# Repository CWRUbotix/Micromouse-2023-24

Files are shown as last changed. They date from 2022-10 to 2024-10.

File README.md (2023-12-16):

# Micromouse 2023-24 🐁

A fully autonomous maze-solving not-quite-mouse-sized robot. 

## Folders

```
.
├── LICENSE	     # License (woohoo)
├── README.md    # This file
├── cad          # 3D-models and designs
├── pcb          # Hardware-related designs and component docs
└── software     # Soft/firmware for the robot
```

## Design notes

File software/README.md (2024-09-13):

# Micromouse Software Setup 2025

# Table of Contents

1. [Setup Git Repo](#setup-git-repo)

2. [Install Arduino IDE](#install-arduino-ide)
    1. [Enable Teensy Support](#enable-teensy-support)
3. [Install Mouse Simulator](#install-mouse-simulator)
    1. [Install C Compiler GCC](#install-c-compiler-gcc)
    2. [Run the Simulator](#to-run-the-simulator)
    3. [OPTIONAL - Install QT Creator](#optional-install-qt-creator)

# Setup Git Repo
If you already have Git or Git Desktop installed, you can skip to [Cloning the Git Repo](#cloning-the-git-repo)  
If you want do version control from the command line and forgo opening another application to push your changes to the repository, just download [Git](https://git-scm.com/downloads).  
Otherwise, if you'd like to forgo using the command line and use a GUI instead, install [GitHub Desktop](https://desktop.github.com/download/) in addition to Git.  
## Cloning the Git Repo
Open up a terminal like `Git Bash`, and `cd` from the current directory to the directory that you want to have the repository
```bash
cd folder/folder/desired_folder
```
And from there, type this into your terminal to clone the repo
```bash
git clone https://github.com/CWRUbotix/Micromouse-2023-24.git
```
You should now have a folder called `Micromouse-2023-24` in your current directory
# Install Arduino IDE
If you don't already have it installed, go [here](https://www.arduino.cc/en/software) to install the Arduino IDE
## Enable Teensy Support
Steps to enable Teensy Support are [here](https://www.pjrc.com/arduino-ide-2-0-0-teensy-support/).  
After following the instructions on that page, click `File` and click `Preferences`.  
Then click the `Browse` button next to `Sketchbook Location`.  
This will determine where your Arduino libraries and sketches are saved.  
You should go ahead and change this to where you have the Micromouse repository saved.  
# Install Mouse Simulator
To install the simulator we currrently use for the mouse, go [here](https://github.com/mackorone/mms#download), note the instructions forr each operating system.  
Then click the link to `releases` and install it for windows/mac.  
Once you have it installed, you'll need to extract it. If you don't have WinRAR installed, you may be able to use windows file explorer to extract it. Otherwise, you'll need to install [WinRAR](https://www.win-rar.com/download.html?&L=0)  
## Install C Compiler GCC
To run the simulator, you need to install the C compiler GCC.  
To do so, follow the instructions on this cool [medium article](https://dev.to/gamegods3/how-to-install-gcc-in-windows-10-the-easier-way-422j).  
### To run the Simulator
Navigate to the mms folder you installed and double click on `mms.exe`  
From there, click the plus icon under `Config` in the top right, and fill in the boxes according to the image below  


If you click `OK`, then click `Build` and `Run`, it should run the currrent algorithm we have for the robot.

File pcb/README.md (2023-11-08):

# Hardware Docs & Meeting Notes

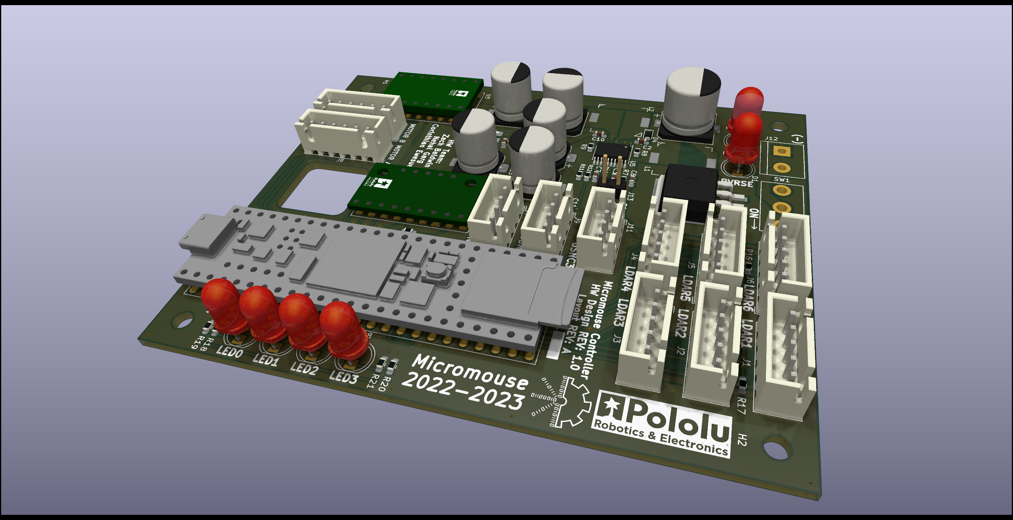
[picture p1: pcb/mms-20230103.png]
Rendering of the Micromouse PCB in KiCad


The PCB for this year's Micromouse robot makes use of several pre-built modules to simplify the pCB design. The motor drivers, accel/gyro, and Teensy 4.1 are "socketed" using headers while a custom buck/boost converter is used to generate the 5V and 3V3 rails needed by everything.

## 10/9

### TODO

* find gyro - probably i squared c 
* create Teensy on kicad
* find / reverse engineering motor controllers (DRV8871) schematics

### Parts :

* Should have
  - 6 sensors with 2 pins for i squared c and ground (software placement)
  - A voltage regulator 
  - i squared c "I2C" - protocol that is bi directional 
  - JST connectors
  - Teensy 4.1 : powerful microcontroller 
  - motor controllers : h bridge clip with capacitors 
    + can integrate into the board or kept it separate and connect manually
    + jst connectors
  - power switch
  - reset switch
  - gyro : type of sensor 
* Nice to have
  - battery protection : not required but nice to have
  - dip switches to go into debugging mode (nice to have)
  - leds for general debugging (nice to have)
  - whiteboard for labeling (nice to have)

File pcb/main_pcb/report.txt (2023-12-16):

Change symbol #PWR0110 from 'power:+3.3V' to 'power:+3.3V': OK

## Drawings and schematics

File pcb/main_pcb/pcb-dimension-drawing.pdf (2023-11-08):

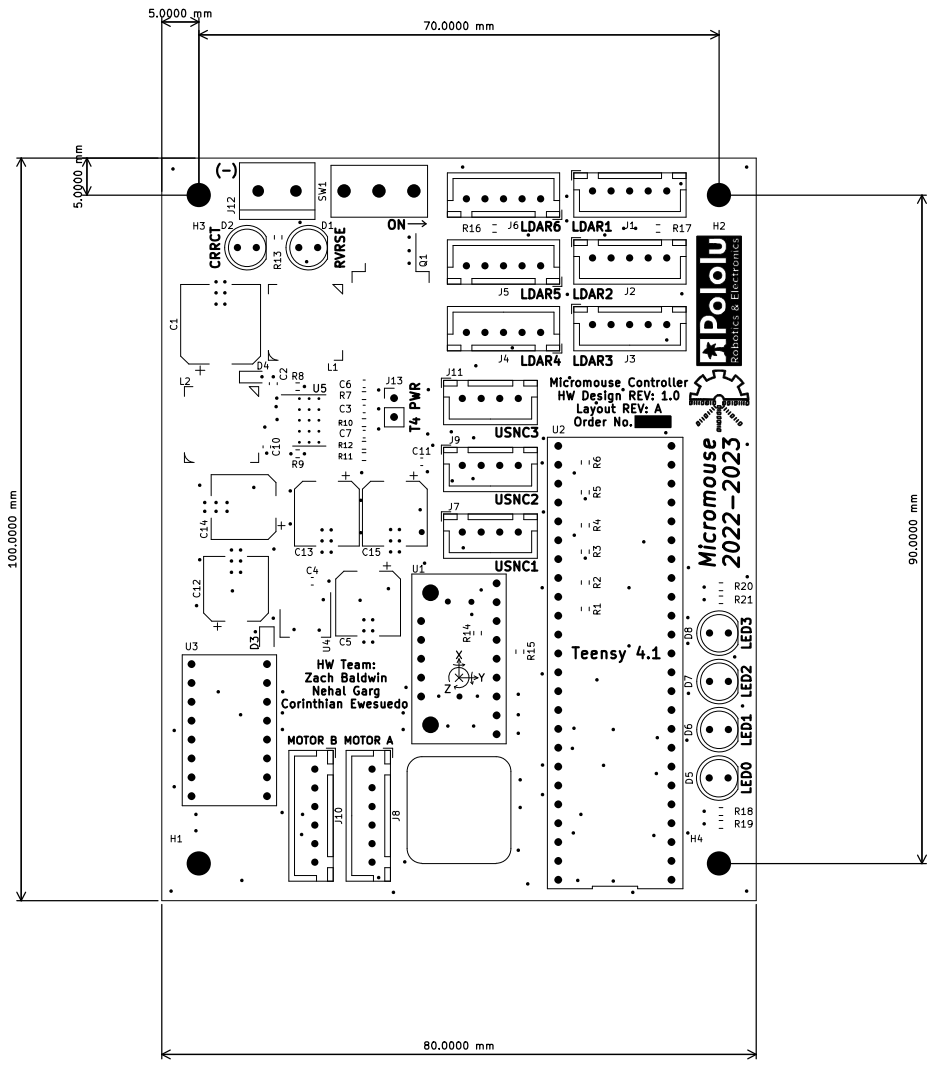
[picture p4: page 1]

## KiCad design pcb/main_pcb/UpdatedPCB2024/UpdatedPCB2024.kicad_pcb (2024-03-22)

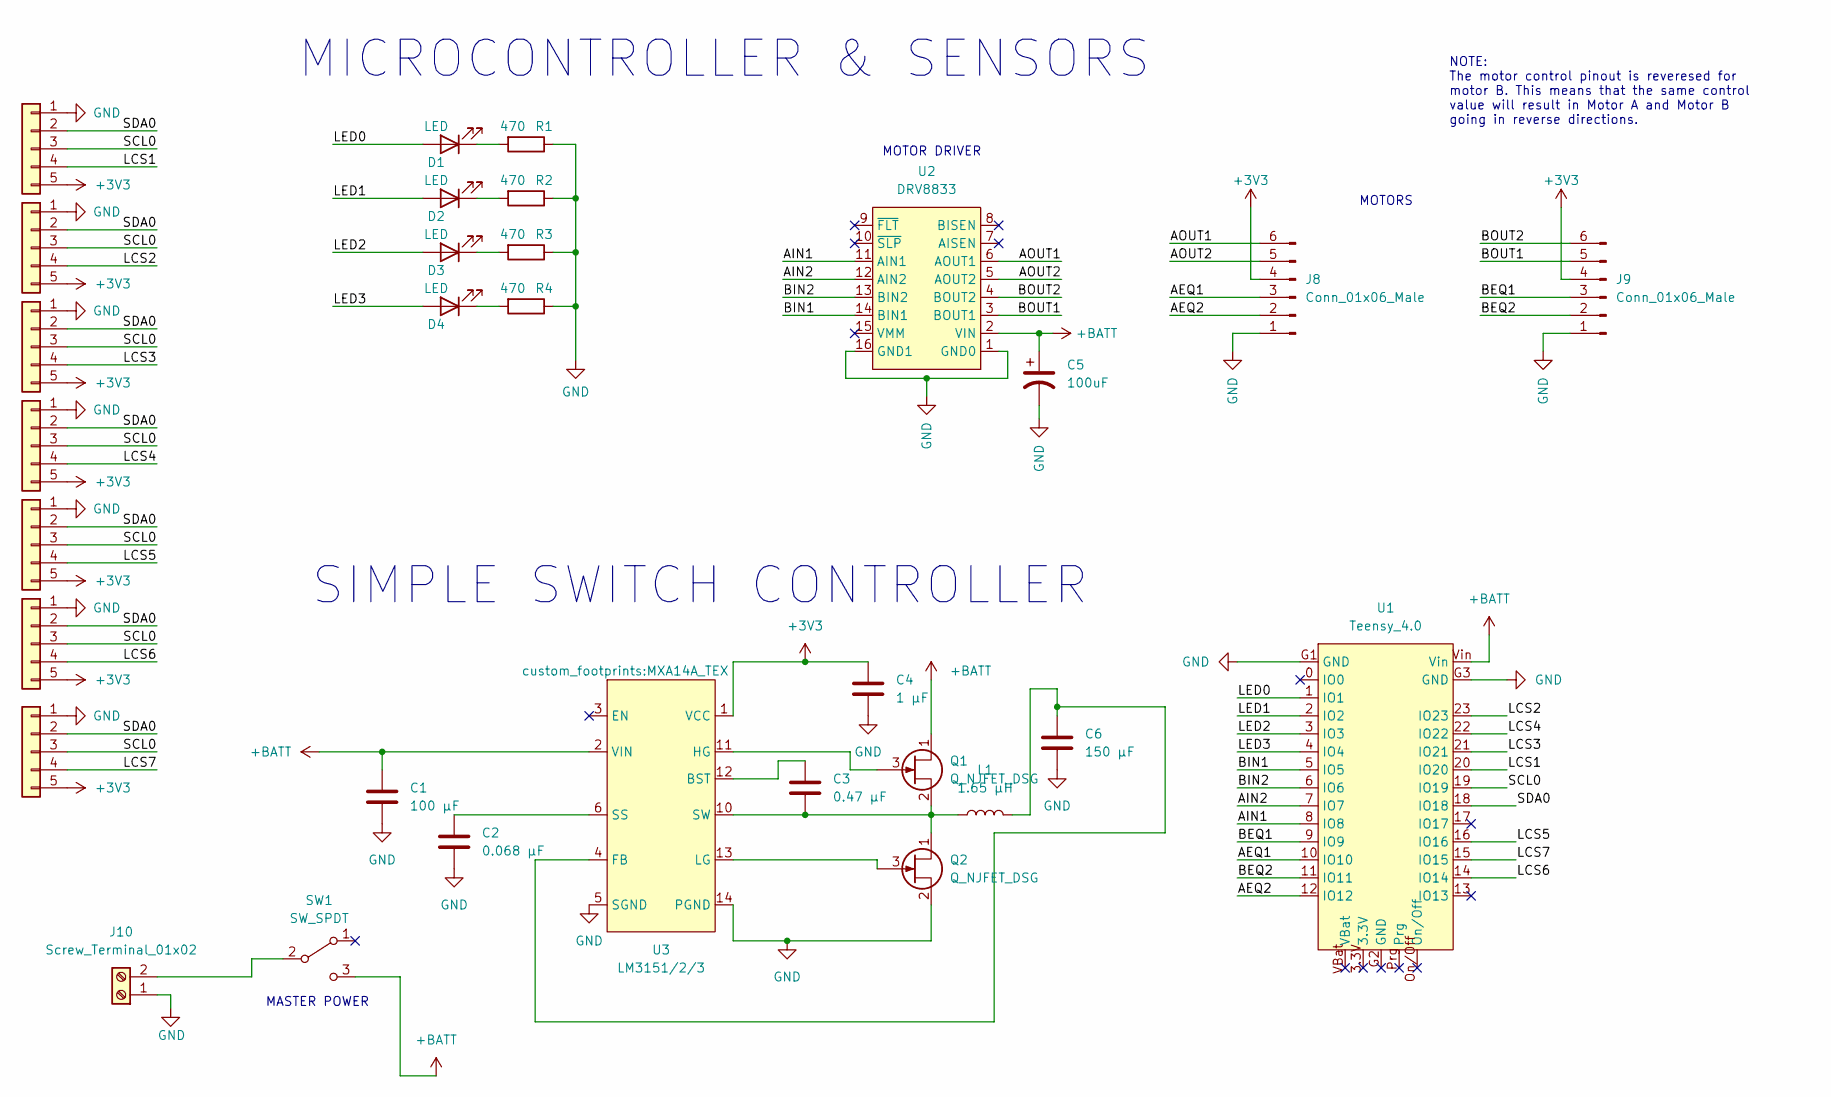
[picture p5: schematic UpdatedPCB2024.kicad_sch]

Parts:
C1: 100 µF; CHEMI-JA0
C2: 0.068 µF; 0603_AVX
C3: 0.47 µF; CAP_2012_TDK
C4: 1 µF; CAPC220145_100N_KEM
C5: 100uF; CP_Elec_8x10.5
C6: 150 µF; PCAP_EEF_SX_PAN
D1, D2, D3, D4: LED; LED_D5.0mm
J1, J2, J3, J4, J5, J6, J7: Conn_01x05; JST_XH_B5B-XH-A_1x05_P2.50mm_Vertical
J8, J9: Conn_01x06_Male; JST_XH_B6B-XH-A_1x06_P2.50mm_Vertical
J10: Screw_Terminal_01x02; TerminalBlock_bornier-2_P5.08mm
L1: 1.65 µH; HA3778-AL
Q1, Q2: Q_NJFET_DSG; TRANS_RTR020N_ROM
R1, R2, R3, R4: 470; R_0603_1608Metric_Pad0.98x0.95mm_HandSolder
SW1: SW_SPDT; SW_SPDT_NKK_MS12AANW03
U1: Teensy_4.0; Teensy40
U2: DRV8833; DRV_DRV8833_Pololu_2130
U3: LM3151/2/3; MXA14A_TEX

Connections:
+3V3: C4.1, J1.5, J2.5, J3.5, J4.5, J5.5, J6.5, J7.5, J8.4, J9.4, U3.1 (VCC)
+BATT: C1.1, C5.1, Q1.1 (D), SW1.3 (C), U1.Vin, U2.2 (VIN), U3.2 (VIN)
/AEQ1: J8.3, U1.10 (IO10)
/AEQ2: J8.2, U1.12 (IO12)
/AIN1: U1.8 (IO8), U2.11 (AIN1)
/AIN2: U1.7 (IO7), U2.12 (AIN2)
/AOUT1: J8.6, U2.6 (AOUT1)
/AOUT2: J8.5, U2.5 (AOUT2)
/BEQ1: J9.3, U1.9 (IO9)
/BEQ2: J9.2, U1.11 (IO11)
/BIN1: U1.5 (IO5), U2.14 (BIN1)
/BIN2: U1.6 (IO6), U2.13 (BIN2)
/BOUT1: J9.5, U2.3 (BOUT1)
/BOUT2: J9.6, U2.4 (BOUT2)
/LCS1: J1.4, U1.20 (IO20)
/LCS2: J2.4, U1.23 (IO23)
/LCS3: J3.4, U1.21 (IO21)
/LCS4: J4.4, U1.22 (IO22)
/LCS5: J5.4, U1.16 (IO16)
/LCS6: J6.4, U1.14 (IO14)
/LCS7: J7.4, U1.15 (IO15)
/LED0: D1.2 (A), U1.1 (IO1)
/LED1: D2.2 (A), U1.2 (IO2)
/LED2: D3.2 (A), U1.3 (IO3)
/LED3: D4.2 (A), U1.4 (IO4)
/SCL0: J1.3, J2.3, J3.3, J4.3, J5.3, J6.3, J7.3, U1.19 (IO19)
/SDA0: J1.2, J2.2, J3.2, J4.2, J5.2, J6.2, J7.2, U1.18 (IO18)
GND: C1.2, C2.2, C4.2, C5.2, C6.2, J1.1, J2.1, J3.1, J4.1, J5.1, J6.1, J7.1, J8.1, J9.1, J10.1, Q2.2 (S), R1.1, R2.1, R3.1, R4.1, U1.G1 (GND), U1.G3 (GND), U2.1 (GND0), U2.16 (GND1), U3.5 (SGND), U3.14 (PGND)
unnamed: D1.1 (K), R1.2
unnamed: D2.1 (K), R2.2
unnamed: D3.1 (K), R3.2
unnamed: D4.1 (K), R4.2
unnamed: J10.2, SW1.2 (B)
unnamed: Q1.3 (G), U3.11 (HG)
unnamed: C3.2, L1.2, Q1.2 (S), Q2.1 (D), U3.10 (SW)
unnamed: Q2.3 (G), U3.13 (LG)
unnamed: C3.1, U3.12 (BST)
unnamed: C6.1, L1.1, U3.4 (FB)
unnamed: C2.1, U3.6 (SS)

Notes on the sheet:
MOTORS
MOTOR DRIVER
MICROCONTROLLER & SENSORS
SIMPLE SWITCH CONTROLLER
NOTE: The motor control pinout is reveresed for motor B. This means that the same control value will result in Motor A and Motor B going in reverse directions.
MASTER POWER

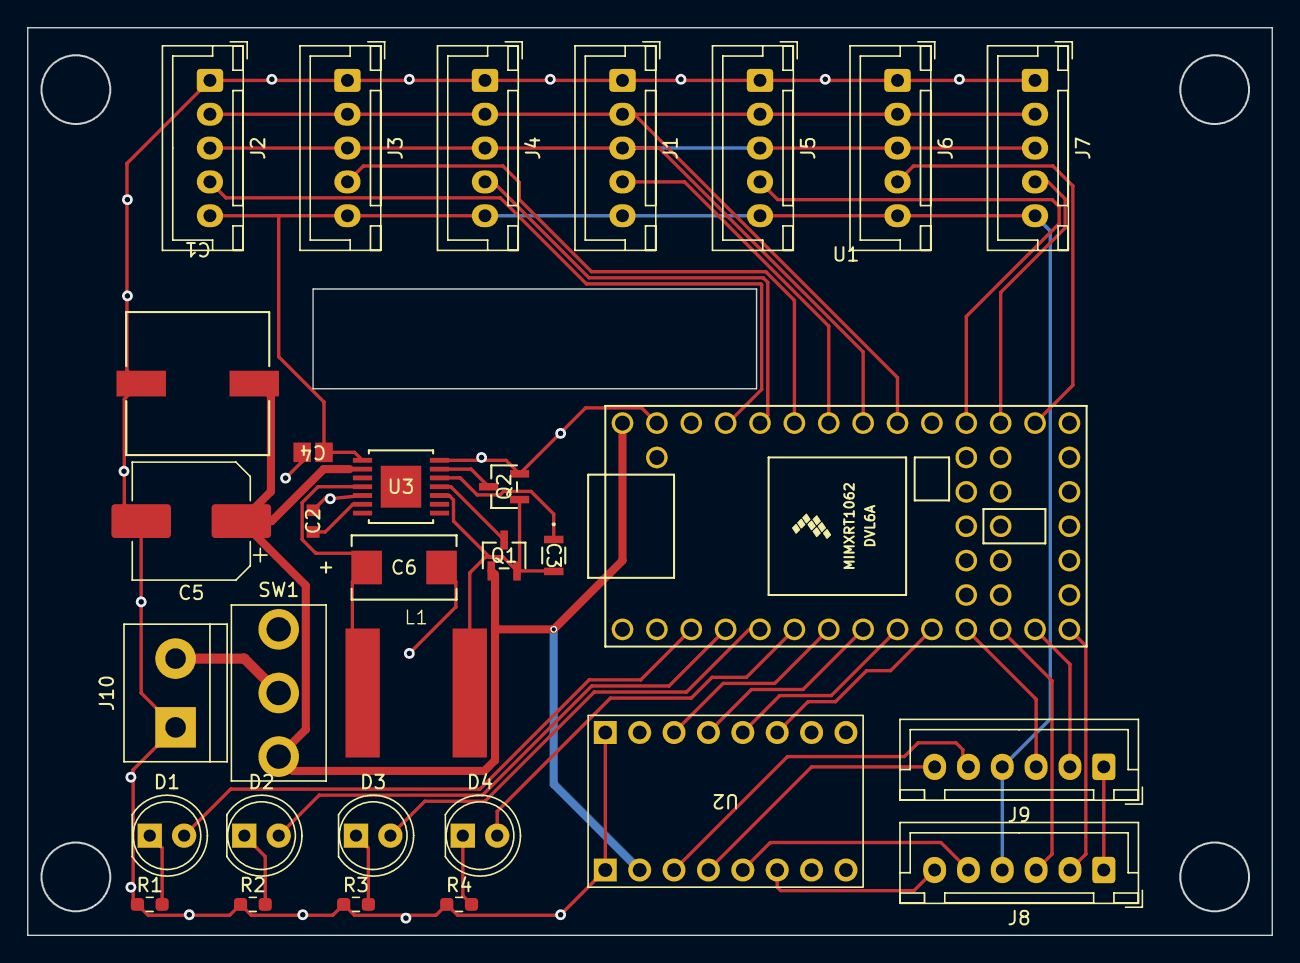
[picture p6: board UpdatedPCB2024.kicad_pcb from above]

Board: 2 copper layers, 91.9 x 67.1 mm, 31 parts (0 on the bottom side), 39 nets.

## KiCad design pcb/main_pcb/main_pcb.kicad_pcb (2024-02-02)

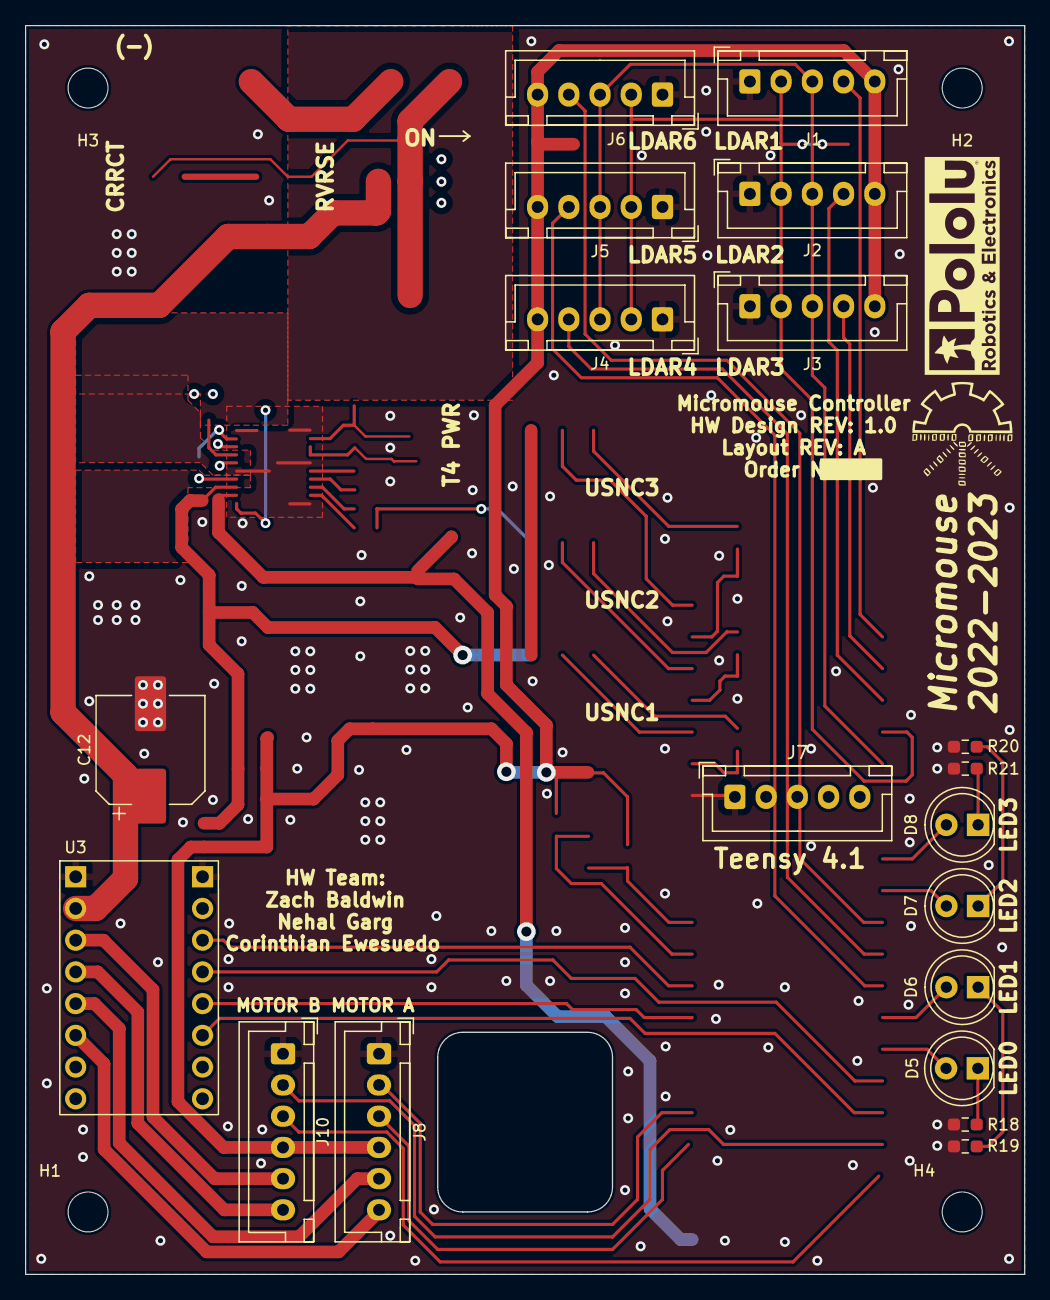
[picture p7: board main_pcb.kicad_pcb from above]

Board: 2 copper layers, 80.0 x 100.0 mm, 23 parts (0 on the bottom side), 13 nets.

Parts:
C12: 100uF; CP_Elec_8x10.5
D5, D6, D7, D8: LED; LED_D5.0mm
H1, H2, H3, H4: MountingHole; MountingHole_3.2mm_M3
J1, J2, J3, J4, J5, J6, J7: Conn_01x05; JST_XH_B5B-XH-A_1x05_P2.50mm_Vertical
J8, J10: Conn_01x06_Male; JST_XH_B6B-XH-A_1x06_P2.50mm_Vertical
R18, R19, R20, R21: 470; R_0603_1608Metric_Pad0.98x0.95mm_HandSolder
U3: DRV8833; DRV_DRV8833_Pololu_2130

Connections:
+3V3: J1.5, J2.5, J3.5, J4.5, J5.5, J6.5, J7.5, J8.4, J10.4
+BATT: C12.1, U3.2 (VIN)
/microcontroller/AOUT1: J8.6, U3.6 (AOUT1)
/microcontroller/AOUT2: J8.5, U3.5 (AOUT2)
/microcontroller/BOUT1: J10.5, U3.3 (BOUT1)
/microcontroller/BOUT2: J10.6, U3.4 (BOUT2)
/microcontroller/SCL2: J1.3, J2.3, J3.3, J4.3, J5.3, J6.3, J7.3
/microcontroller/SDA2: J1.2, J2.2, J3.2, J4.2, J5.2, J6.2, J7.2
GND: C12.2, J1.1, J2.1, J3.1, J4.1, J5.1, J6.1, J7.1, J8.1, J10.1, R18.1, R19.1, R20.1, R21.1, U3.1 (GND0), U3.16 (GND1)
unnamed: D5.1 (K), R18.2
unnamed: D6.1 (K), R19.2
unnamed: D7.1 (K), R20.2
unnamed: D8.1 (K), R21.2

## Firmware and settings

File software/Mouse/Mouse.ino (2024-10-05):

/* --- Includes --- */
// Wire.h for I2C communication with TCA chip and LiDAR
#include <Wire.h>
// Arduino standard encoder library
#include <Encoder.h>
// Adafruit library for VL6180X LiDAR sensor
#include "Adafruit_VL6180X.h"
// Pin definitions
#include "micromouse_pins_2023.h"
// Robot Logic and Algorithm definitions
#include "Algo/FMicro.cpp"
/* ---- Defines ---- */
typedef enum motor_t {
    LEFT_MOTOR = 0,
    RIGHT_MOTOR = 1
} motor_t;

// #define TEST
#undef log
#undef logf
#undef logln

#ifdef TEST
  #define log(...) Serial.print(__VA_ARGS__)
  #define logf(...) Serial.printf(__VA_ARGS__)
  #define logln(...) Serial.println(__VA_ARGS__)
  #define LOGGING 1
#else
  #define log(...)
  #define logf(...)
  #define logln(...)
  #define LOGGING 0
#endif

#define POWER_DEADBAND 12

#define LIDAR_COUNT 4
#define LIDAR_ADDR_BASE 0x50

// The physical distance between the sensors
#define LIDAR_SEPERATION 123 // 123 mm between sensors

int ANGLE_TOLERANCE = 0;
int speed = 32;

const double encoderTicks = 12;
const double gearRatio = 150;
const double wheelSeparation = 95; // 95 mm between wheels
const double wheelRadius = 30; // 30 mm radius
const double turnRatio = (wheelSeparation / 2.0) / wheelRadius / 360 * gearRatio * encoderTicks; // degree to encoder tick conversion ratio

// The LiDAR sensors return a running average of readings,
//  so when we move past a wall, the LiDAR returns a value greater than the previous value but less than an overflow.
// (After a certain amount of time, the running average overflows the maximum and only then does the LiDAR throw a read error)
// If the LiDAR is greater than this value, we assume that it's not sensing the wall.
#define SENSOR_RANGE_MAX 110

// When centered, there should be 60mm in front of the ultrasonic - changed to 90 for more leeway and turn space
#define ULTRASONIC_FRONT 90

// Squares are 10in by 10in, but we work in mm. 10in = 254 mm
#define SQUARE_SIZE 254

/* ---- User Variables ---- */

// GPIO pin numbers for the CS line on each LiDAR sensor
// We have another 2 pins on the board, but nothing's plugged into them
const int lidar_cs_pins[LIDAR_COUNT] = {LIDAR_CS1, LIDAR_CS2, LIDAR_CS3, LIDAR_CS4};

Adafruit_VL6180X lidar_sensors[LIDAR_COUNT];

bool back_right_errored, front_right_errored, back_left_errored, front_left_errored;
uint8_t back_right;
uint8_t front_right;
uint8_t back_left;
uint8_t front_left;

Encoder rightEncoder (ENCODER_RIGHT_1, ENCODER_RIGHT_2);
Encoder leftEncoder (ENCODER_LEFT_1, ENCODER_LEFT_2);

double ultrasonic;
double ultrasonic_running_average;
const double ultrasonic_ave_factor = 0.1;

// Magic constant that converts the time the ultrasonic takes to read the sensors into millimeters
// Based on the speed of sound
double ultrasonic_distance_factor = 0.17;

bool ultrasonic_errored;

/**
 * Convert a value in range [-127..127] to a motor power value
 *
 * @param p The input power [-127..127]
 * @return Output power [0..255]
 */
uint8_t convertPower(int8_t p) {
  if (p == 0) {
    return 255;
  }
  if (p < 0) {
    p = -p;
  }
  return 255 - (((uint8_t) p) * 2);
}

/**
 * Set motor power for a specified motor
 *
 * @param m The motor to modify
 * @param power The power and direction of the motor
 *              (range: [-127..127])
 *              Positive is "forward"
 *              Negative is "backward"
 */
void setMotor (motor_t m, int power) {
  if (power < -127) {
    power = -127;
  }else if (power > 127) {
    power = 127;
  }
  int m1, m2;

  // Determine motor
  if (m == LEFT_MOTOR) {
    m1 = MOTORLEFT_1;
    m2 = MOTORLEFT_2;
  }else if (m == RIGHT_MOTOR) {
    m1 = MOTORRIGHT_1;
    m2 = MOTORRIGHT_2;
  }else {
    return;
  }
  // Set power
  if (power < POWER_DEADBAND && power > -POWER_DEADBAND) {
      analogWrite(m1, 255);
      analogWrite(m2, 255);
  } else if (power > 0) {
      analogWrite(m1, convertPower(power));
      analogWrite(m2, 255);
  } else {
      analogWrite(m1, 255);
      analogWrite(m2, convertPower(power));
  }
}

int wallLeft() {
  front_left = lidar_sensors[3].readRange();
  logf("Left: %d\n", !(lidar_sensors[3].readRangeStatus() != VL6180X_ERROR_NONE || front_left > SENSOR_RANGE_MAX));
  return !(lidar_sensors[3].readRangeStatus() != VL6180X_ERROR_NONE || front_left > SENSOR_RANGE_MAX);
}

int wallRight() {
  front_right = lidar_sensors[2].readRange();
  logf("Right: %d\n", !(lidar_sensors[2].readRangeStatus() != VL6180X_ERROR_NONE || front_right > SENSOR_RANGE_MAX));
  return !(lidar_sensors[2].readRangeStatus() != VL6180X_ERROR_NONE || front_right > SENSOR_RANGE_MAX);
}

int wallFront(){
  digitalWrite(SONIC_TRIG1, HIGH);
  delayMicroseconds(10);
  digitalWrite(SONIC_TRIG1, LOW);
  ultrasonic = pulseIn(SONIC_ECHO1, HIGH) * ultrasonic_distance_factor;
  ultrasonic_errored = ultrasonic > SENSOR_RANGE_MAX;
  logf("Front: %d\n", !(ultrasonic > SENSOR_RANGE_MAX));
  return !(ultrasonic > SENSOR_RANGE_MAX);
}

void updateSensors () {
  // Read the right LIDAR sensors and update their values
  back_right = lidar_sensors[1].readRange();
  back_right_errored = lidar_sensors[1].readRangeStatus() != VL6180X_ERROR_NONE || back_right > SENSOR_RANGE_MAX;
  front_right = lidar_sensors[2].readRange();
  front_right_errored = lidar_sensors[2].readRangeStatus() != VL6180X_ERROR_NONE || front_right > SENSOR_RANGE_MAX;

  // Read the left LIDAR sensors and update their values
  back_left = lidar_sensors[0].readRange();
  back_left_errored = lidar_sensors[0].readRangeStatus() != VL6180X_ERROR_NONE || back_left > SENSOR_RANGE_MAX;
  front_left = lidar_sensors[3].readRange();
  front_left_errored = lidar_sensors[3].readRangeStatus() != VL6180X_ERROR_NONE || front_left > SENSOR_RANGE_MAX;

  // Read front ultrasonic sensor
  digitalWrite(SONIC_TRIG1, HIGH);
  delayMicroseconds(10);
  digitalWrite(SONIC_TRIG1, LOW);
  ultrasonic = pulseIn(SONIC_ECHO1, HIGH) * ultrasonic_distance_factor;
  ultrasonic_errored = ultrasonic > SENSOR_RANGE_MAX;
  // And keep a running average
  if (!ultrasonic_errored) {
    ultrasonic_running_average = ultrasonic * ultrasonic_ave_factor + ultrasonic_running_average * (1 - ultrasonic_ave_factor);
  }

  // logf("Ultrasonic: %f (avg: %f); back_left (%d): %d, front_right (%d): %d, back_left (%d): %d, front_left (%d): %d\n", ultrasonic, ultrasonic_running_average, back_right_errored, back_right, front_right_errored, front_right, back_left_errored, back_left, front_left_errored, front_left);
}

// p_controller(80.0, currentAngle, 0, -127.0, 127.0);
double p_controller(double p, double current, double goal, double min, double max) {
  double out = (goal - current) * p;
  if (out > max) {
    out = max;
  }else if (out < min) {
    out = min;
  }
  return out;
}

/**
 * Counter-clockwise is a positive angle
 * @return angle given by lidar sensors
 */

double getAngle()
{
  // arctan((lidarDistanceBL - lidarDistanceFL) / lidarSeparation);
  // Average left and right sensors
  double leftAngle = -atan2(front_left - back_left, LIDAR_SEPERATION);
  double rightAngle = atan2(front_right - back_right, LIDAR_SEPERATION);
  // logf("left angle: %f\tright angle: %f; ", leftAngle * 180.0 / PI, rightAngle * 180.0 / PI);

  if ((back_left_errored || front_left_errored) && (back_right_errored || front_right_errored)) {
    // If we have no good data, assume we're going straight
    // logf("Using 0 as angle\n");
    return 0;
  } else if (back_left_errored || front_left_errored) {
    // logf("Using right angle\n");
    return rightAngle;
  } else if (back_right_errored || front_right_errored) {
    // logf("Using left angle\n");
    return leftAngle;
  } else {
    // logf("Averaging angles\n");
    return (leftAngle + rightAngle) / 2;
  }
}

/**
 * Turn robot by a given angle in place
 *
 * @param angle     The angle to turn (in degrees)
 * @param direction The direction to turn (LEFT or RIGHT)
 */
void turn(double angle, turning_direction_t direction) {
  // Encoder to turn
  Encoder *turnEncoder;
  Encoder *otherTurnEncoder;

  // target point
  double target = angle * turnRatio;

  // Direction constant
  int dir = 1;

  if (direction == LEFT)
  {
    // Turn left
    turnEncoder = &rightEncoder;
    otherTurnEncoder = &leftEncoder;
  } else {
    // Turn righ
    turnEncoder = &leftEncoder;
    otherTurnEncoder = &rightEncoder;
    dir = -1;
  }

  turnEncoder->write(0);
  otherTurnEncoder->write(0);

  // Turn right wheel backwards if left, forwards if right
  // Scale by 0.7 to compensate for over-volted motors
  setMotor(RIGHT_MOTOR, 45.125 * dir * 0.7);
  // Turn left wheel forwards if left, backwards if right
  setMotor(LEFT_MOTOR, -45.125 * dir * 0.7);

  // Turn until within margin of error

  int encoderAverage;
  do {
    encoderAverage = (turnEncoder->read() - otherTurnEncoder->read()) / 2;
  } while (turnEncoder->read() < target - ANGLE_TOLERANCE);

  // Stop both motors
  setMotor(RIGHT_MOTOR, 0);
  setMotor(LEFT_MOTOR, 0);
}

/**
 * Turn robot by a given angle along a circular path
 * 
 * @param angle     The angle to turn (in degrees)
 * @param direction The direction to turn (LEFT/RIGHT)
 */
void movingTurn(double angle, turning_direction_t direction) {
  Encoder *turnEncoder;
  Encoder *otherTurnEncoder;

  double turnRatio = (SQUARE_SIZE + wheelSeparation) / 2.0 / wheelRadius / 360 * gearRatio * encoderTicks; // degree to encoder tick conversion ratio

  double target = angle * turnRatio;

  double FAST_SPEED = 45.125 * (SQUARE_SIZE + wheelSeparation) / wheelSeparation * 0.35;
  double SLOW_SPEED = 45.125 * (SQUARE_SIZE - wheelSeparation) / wheelSeparation * 0.35;

  if(direction == LEFT){
    turnEncoder = &rightEncoder;
    otherTurnEncoder = &leftEncoder;
    target = target * 10.5 / 12; // correction
    turnEncoder->write(0);
    otherTurnEncoder->write(0);
    setMotor(RIGHT_MOTOR, FAST_SPEED);
    setMotor(LEFT_MOTOR, SLOW_SPEED);
  }
  else{
    turnEncoder = &leftEncoder;
    otherTurnEncoder = &rightEncoder;
    target = target * 9 / 12; // correction
    turnEncoder->write(0);
    otherTurnEncoder->write(0);
    setMotor(RIGHT_MOTOR, SLOW_SPEED);
    setMotor(LEFT_MOTOR, FAST_SPEED);
  }

  do {
    // wait
  } while (turnEncoder->read() < target - ANGLE_TOLERANCE);

  setMotor(RIGHT_MOTOR, 0);
  setMotor(LEFT_MOTOR, 0);
}

/*
void movingTurn(double angle, turning_direction_t dir){
  Encoder *turnEncoder;
  Encoder *otherTurnEncoder;

  leftEncoder.write(0);
  rightEncoder.write(0);

  double ratio =  (SQUARE_SIZE/10 + wheelSeparation)/(SQUARE_SIZE/10 - wheelSeparation);
  double max = 50;
  int target = 1800;


  double FAST_SPEED = max*ratio/(ratio + 1);
  double SLOW_SPEED = max*1/(ratio + 1);
  
  if(dir == LEFT){
    turnEncoder = &rightEncoder;
    otherTurnEncoder = &leftEncoder;
    setMotor(RIGHT_MOTOR, FAST_SPEED);
    setMotor(LEFT_MOTOR, SLOW_SPEED);
  }
  else{
    turnEncoder = &leftEncoder;
    otherTurnEncoder = &rightEncoder;
    setMotor(RIGHT_MOTOR, SLOW_SPEED);
    setMotor(LEFT_MOTOR, FAST_SPEED);
  }
  int encoderAverage = 0;
    do {
      encoderAverage = (turnEncoder->read() - otherTurnEncoder->read()) / 2;
    } while (encoderAverage < target);

  setMotor(RIGHT_MOTOR, 0);
  setMotor(LEFT_MOTOR, 0);
}*/

// Rotate 90 degrees right
void turnRight(){
  logln("Turning Right");
  turn(90.0 + getAngle() * 180.0 / PI, RIGHT);
}

// Rotate 90 degrees left
void turnLeft(){
  logln("Turning Left");
  turn(90.0 - getAngle() * 180.0 / PI, LEFT);
}

// Rotate 90 degrees right while moving forward
void movingTurnRight(){
  logln("Moving Turn Right");
  movingTurn(90.0 + getAngle() * 180.0 / PI, RIGHT);
}

// Rotate 90 degrees left while moving forward
void movingTurnLeft(){
  logln("Moving Turn Left");
  movingTurn(90.0 - getAngle() * 180.0 / PI, LEFT);
}

// Rotate 45 degrees right
void turnRight45(){
  turn(45.0 + getAngle() * 180.0 / PI, RIGHT);
}

// Rotate 45 degrees left
void turnLeft45(){
  turn(45.0 - getAngle() * 180.0 / PI, LEFT);
}

void turn180(){
  turn(180.0 - getAngle() * 180.0 / PI, LEFT);
}

// Moves the robot forward 1 square in the direction the robot is currently facing
int moveForward(int number) {
  // Reset encoders
  leftEncoder.write(0);
  rightEncoder.write(0);

  // Create angle variables
  double currentAngle, angularVelocity;

  // Create speed variables
  // (currentDistance is the distance inside the current square.)
  double currentDistance = 0;
  double goalDistance = SQUARE_SIZE * number;
  double velocity;

  // Center variables
  double centerVelocity, centerOffset;

  // loop quickly
  while (1) {
    // update currentDistance and currentAngle
    {
      // read LiDARs
      updateSensors();
      // Update angle
      currentAngle = getAngle();

      // Update current distance
      // 4560 ticks per revolution (380:1 gearbox * 12 ticks per rev normally)
      // num revolutions * pi * diameter
      long leftRevs = leftEncoder.read();
      long rightRevs = rightEncoder.read();
      // ((Num ticks of both wheels / 2) / num ticks per revolution) * PI * diameter 
      // Becomes revolutions * mm per revolution
      currentDistance = (((leftRevs + rightRevs) / 2.0) / (gearRatio * encoderTicks)) * PI * 2 * wheelRadius;
    }

    // logf("Moving forward. current: %d, ultra: %d, goal: %d, cond: %d, %d\n", currentDistance, ultrasonic, goalDistance, ultrasonic < 150, ultrasonic > 95);

    // We're also not allowed to break out of the loop (stop going forward), if we're farther than 95 mm from a wall
    // If we think we're there, but we're not, go farther
    if (currentDistance >= goalDistance && ultrasonic < 150 && ultrasonic > 95) {
      logf("Moving goalDistance forward.\n");
      // Increase goal distance such that the ultrasonic ends up ULTRASONIC_FRONT (60mm) away from the wall in front of us
      goalDistance += ultrasonic - ULTRASONIC_FRONT;
      redLights();
    }

    // check if currentDistance and currentAngle are within tolerance
    // For the ultrasonic, 60 is 60 mm from the wall. This is about
    // the distance when the robot is centered in the tile
    if (currentDistance >= goalDistance || (!ultrasonic_errored && ultrasonic < ULTRASONIC_FRONT)) {
      setMotor(LEFT_MOTOR, 0);
      setMotor(RIGHT_MOTOR, 0);
      logf("Stopped. Ultrasonic: %d, %d, %lf\n", !ultrasonic_errored, ultrasonic < ULTRASONIC_FRONT, ultrasonic);
      if(digitalRead(RED_LED) == HIGH)
        digitalWrite(RED_LED, LOW);
      greenLights();
      greenLights();
      break;
    }
 
    // How far away from the center we are
    // Right is positive
    // (ASCII art by Zach)
    // |              | <--  MAZE    |
    // |              |   CENTERLINE |
    // |              |              |
    // |      ERROR   |              |
    // |           \  |              |
    // |           |<>|              |
    // |       +-------+ <--- X ---> |
    // |       | FRONT |             |
    // |       |L  |  R|             |
    // |       |   |   |             |
    // |       | ROBOT |             |
    // |       +-------+             |
    // |       |<- R ->|             |
    // |              |              |
    // |              |              |
    // |              |              |
    // |              |              |
    // |              |              |
    // | <------ MAZE WIDTH -------> |
    //
    //              MAZE WIDTH - R
    // ERROR = X - ----------------
    //                    2
    centerOffset = (double)front_right - (double)front_left;
    if (front_left_errored && front_right_errored) {
        // logf("both errored, setting offset to 0\n");
        centerOffset = 0;
    }else if (front_left_errored) {
        // If we don't have a left value
        // (We're targeting to an offset of 0)
        // sensors are 84 mm apart, maze is 240mm wide
        centerOffset = (double)front_right - (240 - 84) / 2.0;
    }else if (front_right_errored) {
        centerOffset = (240 - 84) / 2.0 - (double)front_left;
    }

    // logf("left %d; right %d: center offset: %f\n", front_left, front_right, centerOffset);

    // p, current, goal, min, max
    // When the angle is 0.1, we need to bump left power by like 5, so P of 20
    // (A positive angle means that we're turned left)
    angularVelocity = p_controller(80.0, currentAngle, 0, -127.0, 127.0);

    // With a distance of 254 (one square), we've chose a P of 12.25
    //  so it saturates velocity for the majority of the distance
    velocity = p_controller(12.25, currentDistance, goalDistance, -speed, speed);

    // With a center off set of 10mm, that's a velocity of 5
    centerVelocity = p_controller(0.5, centerOffset, 0, -50, 50);

    angularVelocity += centerVelocity;

    // NOTE: We're assuming that at angles close to 0, angularVelocity has a linear relationship with velocity.

    // update motor values
    // Scale by 0.7 to compensate for over-volted motors
    int velocityLeft = (int)(-angularVelocity / 2.0 * 0.7) + velocity;
    int velocityRight = (int)(angularVelocity / 2.0 * 0.7) + velocity;

    setMotor(LEFT_MOTOR, velocityLeft);
    setMotor(RIGHT_MOTOR, velocityRight);
  }
  return 0;
}

/* ---- SETUP ---- */
void setup(void) {
  // Debug led on the board itself
  pinMode(DEBUG_LED, OUTPUT);

  pinMode(YELLOW_LED, OUTPUT);
  pinMode(BLUE_LED, OUTPUT);
  pinMode(GREEN_LED, OUTPUT);
  pinMode(RED_LED, OUTPUT);

  digitalWrite(DEBUG_LED, HIGH);

  // Start serial
  Serial.begin(115200);
  logln("Serial ready!");

  // Starts I2C on the default pins (18 (SDA), 19 (SCL))
  // (I think, I can't find docs on it)
  I2C_LIDAR.begin();
  logln("I2C ready!");

  // Setup LiDARs
  for (size_t i = 0; i < LIDAR_COUNT; ++i) {
    pinMode(lidar_cs_pins[i], OUTPUT);
  }
  // Disable all sensors except the first
  for (size_t i = 1; i < LIDAR_COUNT; ++i) {
    digitalWrite(lidar_cs_pins[i], LOW);
  }

  // Set address for each sensor
  // Write the CS line high (turning it on)
  // Set the address
  for (size_t i = 0; i < LIDAR_COUNT; ++i) {
    digitalWrite(lidar_cs_pins[i], HIGH);
    // Pass pointer to the Wire2 object since we're running on I2C bus 2
    if (!lidar_sensors[i].begin(&I2C_LIDAR)) {
      log("Failed init on sensor ");
      logln(i);
    } else {
      lidar_sensors[i].setAddress(LIDAR_ADDR_BASE + i);
    }
  }
  logln("LiDAR sensors ready!");

  pinMode(SONIC_TRIG1, OUTPUT);
  pinMode(SONIC_ECHO1, INPUT);
  logln("Ultrasonic sensor ready!");

  // Setup motors
  pinMode(MOTORLEFT_1, OUTPUT);
  pinMode(MOTORLEFT_2, OUTPUT);
  pinMode(MOTORRIGHT_1, OUTPUT);
  pinMode(MOTORRIGHT_2, OUTPUT);

  setMotor(RIGHT_MOTOR, 0);
  setMotor(LEFT_MOTOR, 0);
  logln("Motors ready!");

  pinMode(START_BUTTON, INPUT);
  int t = 0;
  // Spin until start button is pressed
  // t is ms
  // On for 300 (0-300) off for 500 (300-800)
  while(!digitalRead(START_BUTTON)) {
    if (t == 0) {
      digitalWrite(YELLOW_LED, HIGH);
    }else if (t == 300) {
      digitalWrite(YELLOW_LED, LOW);
    }

    t = (t + 10) % 800;
    delay(10);
  }
  digitalWrite(YELLOW_LED, LOW);

  delay(20); // Switch "debounce"
  
  digitalWrite(LED0, HIGH);
  digitalWrite(LED1, HIGH);
  digitalWrite(LED2, HIGH);
  long pressTime = millis();
  long endPressTime = pressTime;
  while (digitalRead(START_BUTTON)) {
    /* spin, waiting for button release */
    endPressTime = millis();
    if (endPressTime - pressTime > 1000) {
      speed = 25;
      digitalWrite(LED2, LOW);
    }
    if (endPressTime - pressTime > 3000) {
      speed = 40;
      digitalWrite(LED1, LOW);
    }
  } 
  if (endPressTime - pressTime < 1000) {
  }else if (endPressTime - pressTime < 3000) {
  }else {
  }
  delay(500);
  digitalWrite(LED0, LOW);
  digitalWrite(LED1, LOW);
  digitalWrite(LED2, LOW);
  initialize();
}

void coolLights(){
  if(digitalRead(BLUE_LED) == LOW)
    digitalWrite(BLUE_LED, HIGH);
  else
    digitalWrite(BLUE_LED, LOW);
    delay(500);
}

void redLights(){
  if(digitalRead(RED_LED) == LOW)
    digitalWrite(RED_LED, HIGH);
  else
    digitalWrite(RED_LED, LOW);
    delay(10);
}

void greenLights(){
  if(digitalRead(GREEN_LED) == LOW)
    digitalWrite(GREEN_LED, HIGH);
  else
    digitalWrite(GREEN_LED, LOW);
    delay(50);
}
/* ---- MAIN ---- */
void loop() {
// updateSensors();
doRun();
}

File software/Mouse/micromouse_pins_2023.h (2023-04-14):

#ifndef MICROMOUSE_PINS_2023_H
#define MICROMOUSE_PINS_2023_H

// LEDS
#define LED0 5
#define LED1 6
#define LED2 10
#define LED3 11
#define YELLOW_LED LED0
#define BLUE_LED LED1
#define GREEN_LED LED2
#define RED_LED LED3

#define DEBUG_LED 13  // The LED on the teensy board

// I2C BUSES
#define I2C_LIDAR Wire2
#define I2C_GYRO Wire1

// LIDAR /CS PINS
#define LIDAR_CS1 28
#define LIDAR_CS2 26
#define LIDAR_CS3 27
#define LIDAR_CS4 8
#define LIDAR_CS5 7
#define LIDAR_CS6 9

#define SONIC_TRIG1 40
#define SONIC_TRIG2 38
#define SONIC_TRIG3 36
#define SONIC_ECHO1 41 
#define SONIC_ECHO2 39
#define SONIC_ECHO3 37

#define ENCODER_LEFT_1 22
#define ENCODER_LEFT_2 23
#define ENCODER_RIGHT_1 1
#define ENCODER_RIGHT_2 2

#define MOTORLEFT_1 3
#define MOTORLEFT_2 19
#define MOTORRIGHT_1 18
#define MOTORRIGHT_2 4

#define START_BUTTON SONIC_ECHO3
#endif

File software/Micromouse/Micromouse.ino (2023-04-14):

/* --- Includes --- */
// Wire.h for I2C communication with TCA chip and LiDAR
#include <Wire.h>
// Arduino standard encoder library
#include <Encoder.h>
// Adafruit library for VL6180X LiDAR sensor
#include "Adafruit_VL6180X.h"
// Pin definitions
#include "micromouse_pins_2023.h"

/* ---- Defines ---- */
typedef enum motor_t {
    LEFT_MOTOR = 0,
    RIGHT_MOTOR
} motor_t;

#define POWER_DEADBAND 6

#define LIDAR_COUNT 4
#define LIDAR_ADDR_BASE 0x50

// The physical distance between the sensors
#define LIDAR_SEPERATION 123 // 123 mm between sensors

#define ANGLE_TOLERANCE 5

const double wheelSeparation = 9.5;
const double wheelRadius = 3;
const double turnRatio = (wheelSeparation / 2.0) / wheelRadius / 360 * 380 * 12;

// The LiDAR sensors return a running average of readings,
//  so when we move past a wall, the LiDAR returns a value greater than the previous value but less than an overflow.
// (After a certain amount of time, the running average overflows the maximum and only then does the LiDAR throw a read error)
// If the LiDAR is greater than this value, we assume that it's not sensing the wall.
#define SENSOR_RANGE_MAX 110

// When centered, there should be 60mm in front of the ultrasonic
#define ULTRASONIC_FRONT 60

// Squares are 10in by 10in, but we work in mm. 10in = 254mm
#define SQUARE_SIZE 254

// Uncommenting this causes everything to break :/
// void abortAndFlash (void) {
//   setMotor(LEFT_MOTOR, 0);
//   setMotor(RIGHT_MOTOR, 0);

//   while (true) {
//     digitalWrite(BLUE_LED, HIGH);
//     delay(100);
//     digitalWrite(BLUE_LED, LOW);
//     delay(100);
//   }
// }

typedef struct Node {
  int   x;
  int   y;
  bool  closed;
  int   distance; // The length of the path up to this point, this.last.distance + 1
  int   guess;    // The heuristic, usually Manhattan to goal with no walls
  int   score;    //The guess + distance (depending on algo) (lower is better)
  Node *last;     //The parent node, the node from which we discovered this node
} Node;

// A node used in the Flood Fill sub-algorithm
typedef struct FFNode {
  bool closed;
  int x;
  int y;
} FFNode;

#define MAZE_SIZE          10
// 0 - Basic A*
// 1 - Hallway following - if there is only a single open node adjacent to the robot, we go there, regardless of score
// 2 - Greedy heuristic - when calculating score, we value getting close to the center 5x more than staying close to
//                        the start (like a string pulled taunt from two sides, the shortest path values both equally)
// 3 - Greedy heuristic and hallway following
#define MAPPING_MODE       3

// This is the midpoint of the maze
// Okay. The heuristic that A* uses is taxi-cab distance to the pin in the middle of
//  the 4x4 goal in the middle of the maze.
//  This pin is located at (4.5, 4.5) (since we've 0-indexed node locations)
//  However, the distance from the center of any node to 4.5, 4.5, by taxi-cab distance is a whole number
//  To avoid floating point math (I don't like floating point), we multiply by 10
//  (Everywhere else, distances, scores, and node locations are absolute, we only multiple by 10 in h())
#define END_X              45
#define END_Y              45

// Used as parameters to the motor functions
enum turning_direction_t { LEFT, RIGHT };

enum cardinal_t {NORTH, EAST, SOUTH, WEST};

/* ---- User Variables ---- */

// GPIO pin numbers for the CS line on each LiDAR sensor
// We have another 2 pins on the board, but nothing's plugged into them
const int lidar_cs_pins[LIDAR_COUNT] = {LIDAR_CS1, LIDAR_CS2, LIDAR_CS3, LIDAR_CS4};

Adafruit_VL6180X lidar_sensors[LIDAR_COUNT];

uint8_t back_right;
uint8_t front_right;

uint8_t back_left;
uint8_t front_left;

bool back_right_errored, front_right_errored, back_left_errored, front_left_errored;

double ultrasonic;
double ultrasonic_running_average;
const double ultrasonic_ave_factor = 0.1;

// Magic constant that converts the time the ultrasonic takes to read the sensors into millimeters
// Based on the speed of sound
double ultrasonic_distance_factor = 0.17;

bool ultrasonic_errored;

Encoder rightEncoder (ENCODER_RIGHT_1, ENCODER_RIGHT_2);
Encoder leftEncoder (ENCODER_LEFT_1, ENCODER_LEFT_2);

// The maze as a 2D array
// maze[Y][X][1: vertical; 0: horizontal]
// And the number represents the confidence
// So 0 is we have no idea, and positive is wall, and negative is no wall
int maze[11][11][2];

// The list of nodes
// Sorted such that closed nodes are 0..closedNodes-1
// And nodes after that increase in score
// This is the canonical list of nodes, order doesn't matter
// All other nodes are pointers into nodesStatic
Node nodesStatic[MAZE_SIZE * MAZE_SIZE];
// A*'s working list of nodes. 0..closedNodes-1 are closed, and closedNodes..numNodes-1 are open
Node *nodes[MAZE_SIZE * MAZE_SIZE];
int closedNodes = 0;
int numNodes = 0;

//The node the robot is currently at (or that A* thinks we're at)
Node *current = NULL;
//The current goal node
Node *goal;

Node *backPath[MAZE_SIZE * MAZE_SIZE]; // Used to store the path along which we backtrack to get to goal
int backPathLength = 0;

// The main path, once we've solved the maze, the route we use
Node *mainPath[MAZE_SIZE * MAZE_SIZE];
int pathLength = 0;

// Create a robot
// Only stores x, y, and facing direction
struct RobotStruct {
  int x;
  int y;
  cardinal_t facing;
} robot = {
  0, 0, NORTH
};

bool shouldFloodFill = false;
int mappingMode = MAPPING_MODE;

/* ---- User Functions ---- */

// Moves the robot to a node which is adjacent to the current node
// adjNode is goal, is x: 1, y: 0
void moveRobot(Node *adjNode) {
  // Figure out what direction the node is in
  cardinal_t direction;
  if (adjNode->x + 1 == robot.x) {
    direction = WEST;
  }else if (adjNode->x - 1 == robot.x) {
    direction = EAST;
  }else if (adjNode->y + 1 == robot.y) {
    direction = NORTH;
  }else if (adjNode->y - 1 == robot.y) {
    direction = SOUTH;
  }else if (adjNode->x == robot.x && adjNode->y == robot.y) {
    Serial.println("WARN: moveRobot called with current location");
    return;
  }else {
    Serial.println("AAAAahaaahhhah");
    direction = NORTH;
    // abortAndFlash();
  }

  // Serial.printf("Spinning to direction #%d\n", direction);
  spinTo(direction);

  moveForwardOneSquare();

  robot.x = adjNode->x;
  robot.y = adjNode->y;
}
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

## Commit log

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2022-10-10 Create PCB project
    [mms_main_pcb.kicad_pcb, mms_main_pcb.kicad_sch]
2022-10-10 Rename PCB project files
    [main_pcb.kicad_pcb, main_pcb.kicad_sch]
2022-10-16 added schematics for DRV8871
    [main_pcb.kicad_sch]
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2022-11-05 Add Teensy and motor controller to sch
    [main_pcb.kicad_sch]
2022-11-11 Demonstrate Labels
    [main_pcb.kicad_sch]
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2022-11-19 pcb board
    [main_pcb.kicad_sch]
2022-12-03 Checked pin-outs and added encoders to motor headers.
    [main_pcb.kicad_sch]
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2022-12-17 Update main_pcb.kicad_sch
    add ultrasonic headers
    [main_pcb.kicad_sch]
2022-12-31 Add power regulators to schematic
    [main_pcb.kicad_sch, microcontroller.kicad_sch, power_supply.kicad_sch]
2022-12-31 Annotate & begin footprint assignment
    [main_pcb.kicad_sch, microcontroller.kicad_sch, power_supply.kicad_sch]
2023-01-01 Create footprints for carriers; complete footprint assignment
    [main_pcb.kicad_sch, microcontroller.kicad_sch, power_supply.kicad_sch]
2023-01-03 Complete initial component placement
    [main_pcb.kicad_pcb, microcontroller.kicad_sch, power_supply.kicad_sch]
2023-01-03 Reorganize Teensy connections for optimized routing
    [main_pcb.kicad_pcb, microcontroller.kicad_sch]
2023-01-03 Set up design rules
    [main_pcb.kicad_pcb]
2023-01-03 Complete digital routing
    [main_pcb.kicad_pcb, main_pcb.kicad_sch, microcontroller.kicad_sch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]
2023-01-03 More routing
    [main_pcb.kicad_pcb, main_pcb.kicad_sch, microcontroller.kicad_sch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]
2023-01-03 Complete initial routing
    [main_pcb.kicad_pcb, microcontroller.kicad_sch]
2023-01-03 Complete routing and Silkscreen
    [main_pcb.kicad_pcb, main_pcb.kicad_sch, microcontroller.kicad_sch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]
2023-01-05 Fix many DRC errors; correct motor B sig names
    [main_pcb.kicad_pcb, main_pcb.kicad_sch, microcontroller.kicad_sch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]
2023-01-05 Change 3V3 reg reverse diode footprint
    [main_pcb.kicad_pcb, main_pcb.kicad_sch, power_supply.kicad_sch]
2023-01-06 Generate gerbers
    [main_pcb.kicad_pcb]
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2023-01-20 Add PCB dimensions for mechanical
    [main_pcb.kicad_pcb]
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2023-02-01 Delete software/Arduino-dev/Old Robot Testing directory
    Fixed Folder name change
    [Old Robot Config.ino]
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2023-02-11 Fix bug with setMotor, allow us to go backwards
    [old-robot-wall-follow.ino]
2023-02-11 Start getting PID working
    * Increases motor dead zone size
    * Fixes several bugs with the PID (things not being defined, int division instead of float, etc)
    * PIDs still need tuning
    [old-robot-wall-follow.ino]
2023-02-19 Update Arduino Turn Function.ino
    Added generic turn function that takes an angle input, determines direction from sign, and adjusts to accommodate for error after the turn.
    [Arduino Turn Function.ino]
2023-02-26 Update Arduino Turn Function.ino
    Fixed errors with existing code, wrote untested method to turn using a PID loop, and added Zach's lidar initialization code
    [Arduino Turn Function.ino]
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2023-03-05 Tweaks for new robot (doesn't work right now)
    [micromouse_pins_2023.h, new-robot-wall-follow.ino]
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2023-03-21 Update new robot encoder right pins; fix distance tracking
    [micromouse_pins_2023.h, new-robot-wall-follow.ino]
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2023-03-24 Fix motors for new robot
    [new-robot-wall-follow.ino]
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2023-03-24 Fix types and get angle PID kind of working!
    [new-robot-wall-follow.ino]
2023-03-28 Elegantly stop using sensors that have read errors & remove LPF
    [new-robot-wall-follow.ino]
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2023-04-04 Fix major bug with backPath creation
    [Micromouse.ino]
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2023-04-09 Scale motor power by 0.7
    The motors are 6V motors but we're running that at a max of 9V. This isn't a problem from a hardware perspective, we just don't want to go too fast.
    [Micromouse.ino]
2023-04-10 Add ultrasonic check to not crash into front wall
    [Micromouse.ino]
2023-04-11 Fix 2 bugs and fix forward accumulated error
    * First bug: since the ultrasonic running average was only being updated if there was a wall in front of us, in practice, the average was often less than 60. This meant that this code would stop us when the ultrasonic stopped erroring (i.e. went under 110), when it was only intended to stop us if the ultrasonic was under 60. This was fixed by using the raw ultrasonic instead of the average.
    * Second bug: Turing was accumulating error half the time.
    * Fix forward accumulated error (if we haven't moved as far down a long hallway as we should have) by checking the ultrasonic before we stop moving forward.
    [Micromouse.ino]
2023-04-11 Fix bug with path creation
    [Micromouse.ino]
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2023-04-13 Fix terrible bug with FF
    [Micromouse.ino]
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2023-11-01 Added Teensy 4.0 schematic
    [main_pcb.kicad_sch, microcontroller.kicad_sch]
2023-11-01 Adding LCS branches
    [main_pcb.kicad_sch, microcontroller.kicad_sch]
2023-11-01 Finishing LCS wires
    [main_pcb.kicad_sch, microcontroller.kicad_sch]
2023-11-07 new changes to pcb
    [main_pcb.kicad_sch, power_supply.kicad_sch]
2023-11-08 deleted ultrasonic sensors
    [main_pcb.kicad_sch, microcontroller.kicad_sch, power_supply.kicad_sch]
2023-11-08 changed ultrasonic placement on teensy 4.0
    [main_pcb.kicad_sch, microcontroller.kicad_sch]
2023-11-08 deleted digital 5V power supply
    [main_pcb.kicad_sch, power_supply.kicad_sch]
2023-11-08 title change
    [power_supply.kicad_sch]
2023-11-15 Deleted old 3v3 power supply
    [main_pcb.kicad_sch, microcontroller.kicad_sch, power_supply.kicad_sch]
2023-11-15 simple switcher controller
    [main_pcb.kicad_sch, microcontroller.kicad_sch, power_supply.kicad_sch]
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2023-11-18 Fixed Sim - Maze is intuitive orientation
    [Micro.c]
2023-11-21 adjustment to simple switch controller
    [main_pcb.kicad_sch, microcontroller.kicad_sch, power_supply.kicad_sch]
2023-11-22 ADDED MOSFETS
    [main_pcb.kicad_sch, power_supply.kicad_sch]
2023-12-16 changes to pcb
    [backup5v.kicad_pcb, backup5v.kicad_sch, main_pcb.kicad_pcb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]
2024-01-01 last minute changes
    [main_pcb-B_Cu.gbl, main_pcb-B_Mask.gbs, main_pcb-B_Paste.gbp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]
2024-01-26 Added comments and other misc. fixes
    [Mouse.ino]
2024-02-02 Error corrections
    [main_pcb.kicad_pcb, main_pcb.kicad_sch, microcontroller.kicad_sch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]
2024-02-13 Footprint and labelling
    Added the Teensy40 footprint into the custom-footprints.pretty folder, which will allow us to link the teensy40 footprint to the schematic we have. will still need to be readdressed.
    Changed the raw text on the schematic to labels so that they will be recognized as connections rather than just text.
    [UpdatedPCB2024.kicad_pcb, UpdatedPCB2024.kicad_sch]
2024-02-13 Symbol footprint linking for teensy4
    Changed some numbers and names around so that the footprint properly linked to the symbol for the Teensy4.0
    We still need to assign footprints to the other circuit components that are not yet assigned, as well as update symbols as necessary.
    [UpdatedPCB2024.kicad_sch]
2024-02-14 Fixed multiple user issue
    Previously, when pulled the custom footprints library in the update 2024 pcb section was set to be my specific library path. I changed it to be more general so it should work out of the gate for everyone
2024-02-16 Including footprints for most pcb parts
    [UpdatedPCB2024.kicad_pcb]
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2024-02-16 Fixed some variable types in Mouse.ino
    [Mouse.ino]
2024-02-20 Created L1 footprint
    Created L1 footprint from product datasheet's recommended footprint.
    [UpdatedPCB2024.kicad_pcb, UpdatedPCB2024.kicad_sch]
2024-02-20 fixing errors on PCB as well as readjustments to outline of PCB
    [UpdatedPCB2024.kicad_pcb, UpdatedPCB2024.kicad_sch, backup5v.kicad_sch]
2024-02-23 Simple switch controller layout
    Did the layout for the simple switch controller such that the pathing is easy.
    [UpdatedPCB2024.kicad_pcb, UpdatedPCB2024.kicad_sch]
2024-02-29 Edited schematic + layout
    Changed some pin configurations (made sure SDA and SCL are configured properly, as well as all PWM necessary pins) and began routing. Layout at this point is finalized, needs to be reviewed and appro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
    [UpdatedPCB2024.kicad_pcb, UpdatedPCB2024.kicad_sch]
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2024-03-05 Routing done, DRC pass
    Finsihed layout and routing, filled ground plane, and added vias to tie off ground plane.
    [UpdatedPCB2024.kicad_pcb]
2024-03-06 Generated Gerber file and finished board
    Its done! yippeeee!
    Added some holes, made some routes thicker, reran the filling functions etc. etc.
    [UpdatedPCB2024-B_Cu.gbr, UpdatedPCB2024-B_Mask.gbr, UpdatedPCB2024-B_Paste.gbr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]
2024-03-22 Fixed direction - added constants
    [Mouse.ino]
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2024-03-29 Fixed moving forward by eliminating the multiplying by values of the P controller (#8)
    * Fixed moving forward
    * Fixed moving turn
    [Mouse.ino]
2024-04-14 Made angle Tolerance -30;Now subtract angles in turnLeft
    [Mouse.ino]
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2024-10-05 Revert "Fixed moving forward by eliminating the multiplying by values of the P controller (#8)"
    This reverts commit df265add56fc8e140ef522fb9257ae3f8838fe75.
    [Mouse.ino]
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
